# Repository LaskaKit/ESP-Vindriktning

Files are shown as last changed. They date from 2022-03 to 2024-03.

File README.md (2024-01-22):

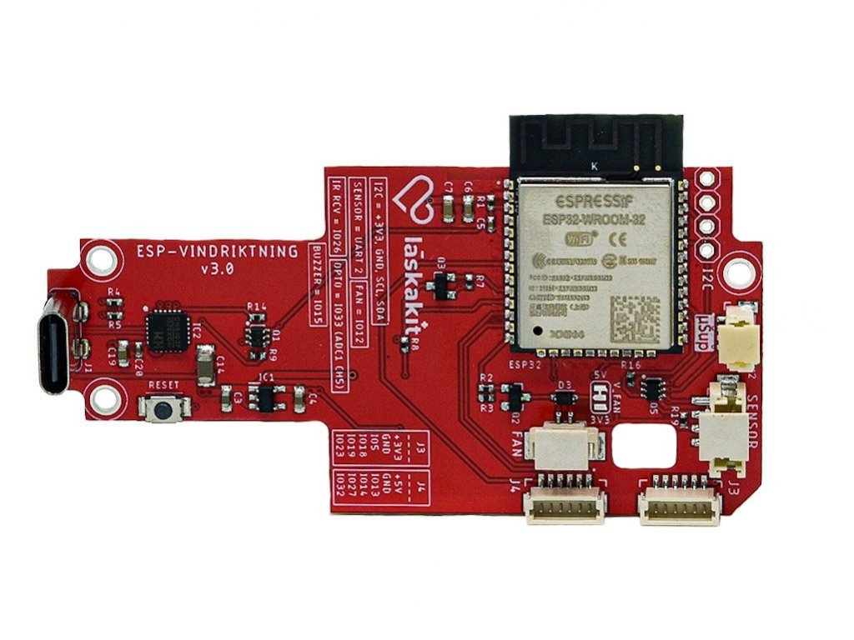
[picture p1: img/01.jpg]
LASKAKIT ESP-VINDRIKTNING

# LASKAKIT ESP-VINDRIKTNING

Ikea Vindriktning is very good and really cheap product which is able to show the quality of air in the room by three LEDs. The original Vindriktning just measure the dust. 
It is not so much for customer. 

We decided to create our own replaced board what will be compatible with the original board but add with Wi-Fi and Bluetooth connectivity, optionaly more sensors, and addressable LEDs. Thanks to this, you get powerful product what may measure the quality of air in the details. 

## Programming
The LASKAKIT ESP-VINDRIKTNING as well as Ikea Vindriktning includes USB-C connector. The orginal board is using the USB-C just for power supply, the ESP-VINDRIKTNING is using USB-C for power and also for programming, because the board includes built-in USB-UART IC as programmer. 

## Connectors
The LASKAKIT ESP-VINDRIKTNING contains six connectors. Two of them are used for original dust sensor - sensor and fan. The third connector is called μŠup and it is compatible with STEMMA QT and Qwiic JST-SH. Thanks to this connector, you can add [temperature/humidity sensor SHT40](https://www.laskakit.cz/laskakit-sht40-senzor-teploty-a-vlhkosti-vzduchu/) or [SCD41 (sensor of CO2/temperature/humidity)](https://www.laskakit.cz/laskakit-scd41-senzor-co2--teploty-a-vlhkosti-vzduchu/) and improve the measurement of air. 
Fourth connector is just 4pin header and you can solder what you want. The 4pin connector includes I2C and power supply with 3.3V. 
The reset of the connectors contains power supply (3.3V) and GPIO which you can use for your purpose. Also the hardware SPI may be used from this connector. 

## LEDs
The number of LEDs is the same with original board. The LEDs are RGB and addressable, it means you can define the color on separately each LED. At the end, you can indicate dust on the first LED, CO2 on the second LED and temperature on third LED. 

## Example codes 
For the fastest development, we prepared a few examples where we show how to easily use LASKAKIT ESP-VINDRIKTNING alone or with SCD41
Use "nodemcu-32s" board in ESPHome and "ESP32 Dev Module" in Arduino IDE.

## Link
The product is available on our store https://www.laskakit.cz/laskakit-esp-vindriktning-esp-32-i2c/
Optional parts: 

SCD41 (CO2/temperature/humidity) https://www.laskakit.cz/laskakit-scd41-senzor-co2--teploty-a-vlhkosti-vzduchu/

SHT40 (temperature/humidity) https://www.laskakit.cz/laskakit-sht40-senzor-teploty-a-vlhkosti-vzduchu/

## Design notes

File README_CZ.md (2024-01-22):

LASKAKIT ESP-VINDRIKTNING
# LASKAKIT ESP-VINDRIKTNING

Ikea Vindriktning je zajímavý a levný produkt firmy Ikea, který dokáže měřit kvalitu vzduchu - prašnost ve vzduchu. A to je všechno.

Rozhodli jsme se vytvořit vlastní desku kterou jenom vyměníš - stačí odšroubovat a přišroubovat 7 šroubků. 
Naše deska LASKAKIT ESP-VINDRIKTNING má konektory na stejném místě jako originální deska, ale navíc obsahuje výkonný a populární čip ESP32, který kromě komunikace s čidlem prachu 
disponuje i možností připojení přes Wi-Fi a Bluetooth. Volitelně můžeš dokoupit i další čidla - SHT40 pro měření teploty a vlhkost nebo SCD41 pro měření CO2/teploty/vlhkosti. 

## Programování
LASKAKIT ESP-VINDRIKTNING stejně jako originální Ikea Vindriktning obsahuje USB-C konektor. U originální desky slouží pouze k napájení, u naší desky je kromě napájení možné ho použít i pro programování.
Stačí jí tedy připojit do USB konektoru a otevřít třeba Arduino IDE. 

## Konektory
LASKAKIT ESP-VINDRIKTNING obsahuje celkem šest konektorů. První dva slouží k připojení originální čidla - čidla prašnosti (čidlo a ventilátor). Třetí [konektor je μŠup](https://blog.laskarduino.cz/predstavujeme-univerzalni-konektor-pro-propojeni-modulu-a-cidel-%ce%bcsup/),
který je kompatibilní s STEMMA QT a Qwiic JST-SH
Díky tomuto konektoru můžeš přidat čidlo [tepoty/vlhkosti SHT40](https://www.laskakit.cz/laskakit-sht40-senzor-teploty-a-vlhkosti-vzduchu/) nebo [SCD41 (čidlo CO2/teploty/vlhkosti)](https://www.laskakit.cz/laskakit-scd41-senzor-co2--teploty-a-vlhkosti-vzduchu/) 
a vytvořit tak komplexní měření kvality vzduchu.
Čtvrtým konektorem je prostý 4pinový hřebínek s I2C a napájením (3.3V)
Zbylé dva konektory obsahují GPIO a 3.3V napájení. GPIO je možné využít s hardwarovým SPI k připojení například displeje. 

## LEDky
Počet LEDek je stejný jako u původní desky. LEDky jsou ale RGB a adresovatelné, to znamená, že každá LEDka dokáže měnit barvu dle dat poslaných přes jednovodičovou sběrnici,
takže první LED může indikovat koncentraci CO2, druhá teplotu, třetí prašnost. 

## Vzorové kódy 
Pro rychlejší start s LASKAKIT ESP-VINDRIKTNING jsme napsali několik vzorových kódů, které můžeš jednoduše upravit pro vlastní potřeby.
Zároveň jsme rozsáhlý článek i na náš blog - https://blog.laskarduino.cz/senzor-prachovych-castic-ikea-vindriktning-vylepseny-o-cidlo-co2-teploty-vlhkosti-bluetooth-wi-fi-komunikaci-a-s-vizualizaci-dat-na-tmep-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
Použij desku "nodemcu-32s" v ESPHome a "ESP32 Dev Module" v Arduino IDE.

## Odkaz
Deska je dostupná na našem e-shopu https://www.laskakit.cz/laskakit-esp-vindriktning-esp-32-i2c/
Další volitelné části: 

SCD41 (CO2/teplota/vlhkost) https://www.laskakit.cz/laskakit-scd41-senzor-co2--teploty-a-vlhkosti-vzduchu/

SHT40 (teplota/vlhkost) https://www.laskakit.cz/laskakit-sht40-senzor-teploty-a-vlhkosti-vzduchu/

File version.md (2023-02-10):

### Version 3.0
- Added, buzzer - GPIO2 pin | Přidán pasivní piezo bzučák - pin GPIO2
- Added, IR remote control receiver - GPIO26 pin | Přidán přijímač IR dálkového ovládání - pin GPIO26
- Added, a jumper to change voltage for fan to 3.3V | Přidána propojka pro přepnutí ventilátoru PM senzoru na 3,3V
- Changed the design of the level converter for the PM sensor | Změna konstrukce převodníku úrovní pro PM senzor
- Changed the USB converter to CH9102F | Změna USB převodníku na CH9102F
- Changed the value of resistor R8 in the logic level converter for the WS2812 LED | Změna hodnoty rezistoru R8 v převodníku logických úrovní pro LED WS2812
- Changed the phototransistor to another type - PT26-51B/TR8 | Změna fototranzistoru na jiný typ - PT26-51B/TR8
- Changed  LDO - BL8071CLBTR33 | Změna LDO stabilizátoru - BL8071CLBTR33
#### Version 2.1
- Phototransistor pin changed from GPIO4 to GPIO33 (ADC1_CHANNEL_5) - cause ADC2 (GPIO4) is not available when using WiFi | Změna pinu fototranzistoru z GPIO4 na GPIO33 (ADC1_CHANNEL_5) - ADC2 (GPIO4) není dostupné při používání WiFi
#### Version 2.0
- Logic level converter for LEDs added | Přidán převodník logické úrovně pro LED

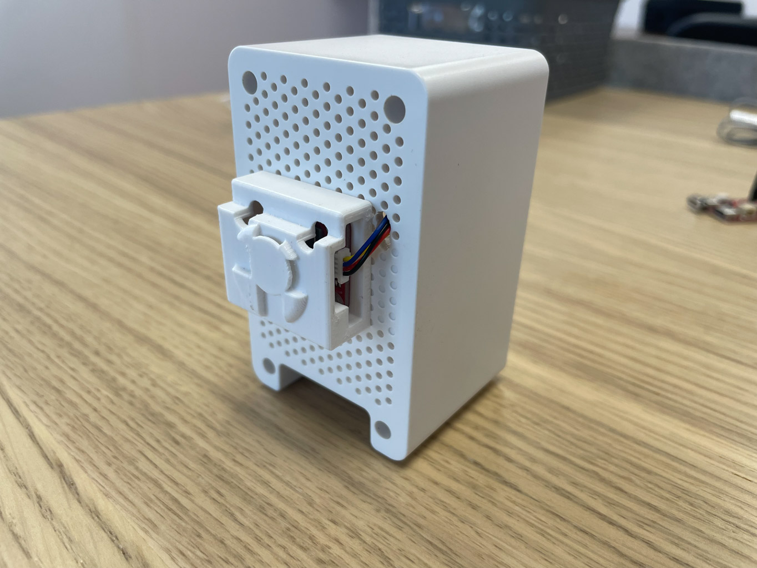
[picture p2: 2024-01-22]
3D/SCD41-on-Vinr.jpg

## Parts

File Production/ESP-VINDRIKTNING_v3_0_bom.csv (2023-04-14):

Comment | Designator | Footprint | LCSC Part #
1.25-2P | FAN | 1.25-2P | C393945
1N5819WS | D3 | SOD323-R | C191023
1k | R8 | R0402
1uF | C3 | C0603
4 7uF | C4 | C0603 | C19666
5k1 | R4 R5 | R0402
10k | R1 R2 R7 R9 R14 R16 R18 R19 | R0402
22uF | C19 | C0603
47uF | C7 | C0603
100k | R3 | R0402
100n | C20 | C0402
100nF | C5 | C0402
100nF | C6 | C0603
100uF | C14 | C1206 | C15008
1x4P-ZH | SENSOR | 1x4P-ZH | C145997
BL8071CLBTR33 | IC3 | SOT223 | C2763399
BSD840NH6327 | Q5 | SC70-6 | C151516
BSS138 | Q2 Q3 | SOT23-3 | C78284
CH9102F | IC2 | QFN24-4X4
ESP32-WROOM-32D | ESP32 | ESP32WROOM32D | C529578
JST-SH-4_VERT | J2 | 1X04_1MM_RA_VERT | C371588
JST-SH-6_VERT | J3 J4 | 1X06_1MM_RA_VERT | C145963
MMDT3904 | Q1 | SC70-6 | C268586
TS-1088R-02026 | RESET | TS1088R02026
1N5819WS | D5 | SOD323-R
2.2uF | C18 | C0402
10k | R10 R12 R13 R17 | R0402
47k | R6 | R0402
100k | R11 | R0402
100n | C8 C11 C12 C13 | C0402
220 | R15 | R0402
BSS138 | Q4 | SOT23-3
FUET-5020 | SG1 | FUET-5020 | C391029
IRM-H638T/TR2 | IR1 | SMD-4_4.0X5.0X2.54P
PT26-21B/CT | PT1 | 1206 | C142317
WS2812B | D1 D2 D4 | WS2812B_2020 | C965555
918-418K2022Y40000 | J1 | 918-418K2022Y40000 | C168704

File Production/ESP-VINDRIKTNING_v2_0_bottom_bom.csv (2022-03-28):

Comment | Designator | Footprint | LCSC Part #
47k | R6 | R0402
100n | C8 C11 C12 C13 | C0402
PT26-21B/TR8 | PT1 | PT26-21B/TR8 | C131248
WS2812B | D1 D2 D4 | WS2812B_2020 | C965555

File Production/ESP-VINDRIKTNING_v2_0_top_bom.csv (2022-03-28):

Comment | Designator | Footprint | LCSC Part #
1.25-2P | FAN | 1.25-2P | C393945
1N5819WS | D3 | SOD323-R | C191023
1uF | C3 | C0603
4 7uF | C4 | C0603 | C19666
5.1k | R4 R5 | R0402 | C25905
10k | R1 R2 R7 R8 R9 R14 | R0402
10μF | C17 | C0603
12MHz | Q6 | 3.2X2.5_KX-7 | C97242
20p | C1 C2 | C0402
47uF | C7 | C0603
100k | R3 | R0402
100n | C9 C10 C15 | C0603
100nF | C5 | C0402
100nF | C6 | C0603
100uF | C14 | C1206 | C15008
470 | R18 R19 | R0402
A1501WV-S-4P | SENSOR | A1501WV-S-4P | C225162
BSS138 | Q2 Q3 | SOT23-3 | C78284
CH340C | IC3 | SOIC16
ESP32-WROOM-32D | ESP32 | ESP32WROOM32D | C82899
HT7833 | LDO | SOT23-5
JST-SH-4_VERT | J2 | 1X04_1MM_RA_VERT | C371588
JST-SH-6_VERT | J3 J4 | 1X06_1MM_RA_VERT | C145963
MMDT3904 | Q1 | SC70-6 | C268586
PI4ULS5V202UEX | IC1 | MSOP8 | C481697
TS-1088R-02026 | RESET | TS1088R02026
918-418K2022Y40000 | J1 | 918-418K2022Y40000 | C168704

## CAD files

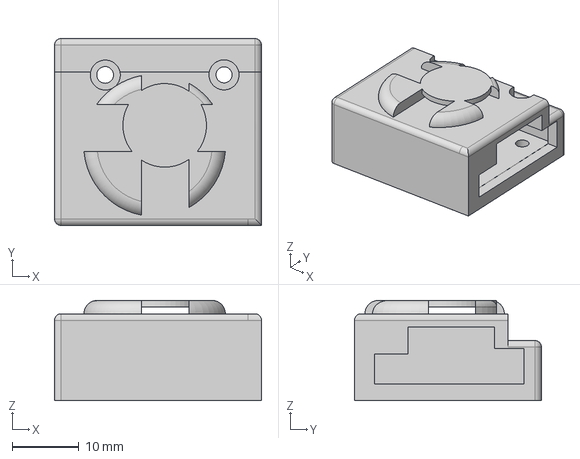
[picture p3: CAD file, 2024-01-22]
3D/LaskaKit SCD41-CO2-Sensor for Vindr.step
31.0 x 28.0 x 15.0 mm

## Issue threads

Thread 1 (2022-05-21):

ESP home

vojtechBohman, 2022-05-21:
Could you show the same integration also for ESP Home?
So far I have only basics. For example on_value_range with PM sensor does not work for me.
```
esphome:
  name: ikea-vindriktning

esp32:
  board: esp32dev
  framework:
    type: arduino

# Enable logging
logger:

# Enable Home Assistant API
api:

ota:
  password: ""

wifi:
  ssid: !secret wifi_ssid
  password: !secret wifi_password

  # Enable fallback hotspot (captive portal) in case wifi connection fails
  ap:
    ssid: "Ikea-Vindriktning"
    password: ""

captive_portal:

uart:
  rx_pin: GPIO16
  tx_pin: GPIO17
  baud_rate: 9600

sensor:
  - platform: pm1006
    id: "vindriktning_pm"
    pm_2_5:
      name: "Particulate Matter 2.5µm Concentration"
    update_interval: 20s
    #on_value_range:
    #  above: 5
    #  below: 10
    #  then:
    #    - light.turn_on: vindriktning_light_1

switch:
  - platform: gpio
    pin: GPIO12
    name: "Fan"
    id: "vindriktning_fan"

light:
  - platform: neopixelbus
    type: GRB
    variant: WS2812
    pin: GPIO25
    num_leds: 3
    name: "Vindriktning Light"
    id: "vindriktning_light"
```

petus, 2022-05-23:
Hello @vojtechBohman , I found that ESPhome is supporting PM1006 (dust sensor) https://esphome.io/components/sensor/pm1006.html
You should just change the GPIO where is UART TX (of PM1006) connected

Konstantin-G, 2022-06-01:
Hi, @bruxy70 did add configuration for ESPHome ;)

Closed 2022-06-01.

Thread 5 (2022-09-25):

Fan noise

magtimmermans, 2022-09-25:
Is there a way to lower the fan noise for example connect it to 3.3 v?

Konstantin-G, 2022-09-26:
Maybe?

magtimmermans, 2022-09-26:
Would be nice. Further great product!

magtimmermans, 2022-09-26:
I thought when you run it on 3v3 it runs slower. But I will try your suggestion as well.

Konstantin-G, 2023-01-04:
In V3.0 we added jumper to change FAN voltage.

Closed 2023-01-04.

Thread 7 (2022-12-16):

V3 Board in Production - PT1 Pad  Issue?

ShockStruck, 2022-12-16:
Hello,

I currently have the V3 Board in Production at JLPCB and they are stating the following:

"Seems the packages of the PT1 parts cannot match the corresponding pads on the PCB board, so we are unable to assemble them."

The part they are trying to place is a PT26-21B-TR8.

Anyone else experience a similar roadblock when producing the boards?

Thanks!

ShockStruck, 2022-12-16:
Latest update from JLPCB:

"Our engineer said the part you choose is correct, but the PCB file is wrong."

Perhaps the V3 Gerber files has some spacing issues on the PT1 pads?

Konstantin-G, 2022-12-17:
PT1 were not designed exactly for this layout, but there no problems whatsoever, we made 500pcs old version. You can replace it with C55976, so we will do to...

Closed 2022-12-17.

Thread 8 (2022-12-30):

V3 Design - VFAN?

ShockStruck, 2022-12-30:
Hello,

Just received 6 PCB's of the V3 varient from JLPCB. Couldn't help but notice that there's no SMD component where labeled "V FAN" 5v/3.3v. is there supposed to be something there? I looked at v2 Schematics, V3 bom and V3 cpl, it appears to not be mentioned . Also noticed that when using the code provided for ESPHome, the lights do not illuminate on the unit. I have found code from bruxy70 on GitHub that resolved this issue.

I should mention that I desoldered the sensor connector from my IKEA boards and placed them into the V3 Board as the connector was backordered.

Thanks for all your help!

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

Konstantin-G, 2023-01-04:
The version 3.0 board is not yet in production and has not been tested. She got onto GitHub by mistake.
V_FAN is a jumper that allows you to power the fan with a voltage of 5V or 3.3V. At 3.3V, the fan has lower rpm and less noise. It has not yet been tested whether switching to 3.3V has any effect on the accuracy of the measurement. By default, the jumper is set to 5V. So there is no need to deal with it.
I have been testing the ESPHome code here for a long time and there is no problem with it. The LEDs are only activated after the sun rises and turn off at sunset. It receives this data from Homeassistant. It might want to fine-tune min_brightness, because at the default value of 0.1 the LED does not light up. We have not yet had the opportunity to examine it in detail and possibly modify it.

Closed 2023-01-04.

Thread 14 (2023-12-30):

Missing files in basic example

ridercz, 2023-12-30:
The `pm1006.h` and `pm1006.cpp` files are missing in basic Arduino example (`VINDRIKTNING`). All other examples have them, but this one does not.

Closed 2024-01-05.

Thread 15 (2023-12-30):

Basic example requires optional CO2 sensor

ridercz, 2023-12-30:
The most basic example (`VINDRIKTNING`) requires optional CO2 sensor. If the sensor is not present, it shows an error.

I think that the basic example should work without any additional hardware and basically mimic the behavior of unmodified unit, so people can build on that example.

Closed 2024-01-05.

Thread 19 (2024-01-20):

Pm1006 measurement fails with basic example

markuswebert, 2024-01-20:
Hi,

I own two VINDRIKTNING ESP v3 boards and two IKEA sensors. When replacing the original board with the laskakit v3 (running the VINDRIKTNING.ino flashed via Arduino IDE) and connecting the pm1006 sensor (power and fan cables), I am not able to read the sensor measurements while starting am stopping the fan as well as reading the ambient light value seems to work. When reading the pm1006 sensor, the log always states Fan ON, measurement failed, fan off.

In the arduino IDE, I set the board ESP32 DEV Module. I also tried both laskakit boards with both ikea sensors.

Do you have a hint for me on how to solve that? Thanks!

Bascht74, 2024-01-20:
I am using this configuration for esphome

`substitutions:
  devicename: luftegwohnzimmer
  upper_devicename: Luftsensor EG Wohnzimmer
  device_description: "IKEA LaskaKit ESP-VINDRIKTNING ESP-32 I2C"

globals:
   - id: max_brightness
     type: float
     restore_value: no
     initial_value: '0.5'
   - id: min_brightness
     type: float
     restore_value: no
     initial_value: '0.1'

esphome:
  name: ${devicename}
  friendly_name: ${upper_devicename}
  comment: "${device_description}"
  on_boot:
    priority: 240
    then:
        - light.turn_on:
            id: status
            brightness: 0%

esp32:
  board: nodemcu-32s
  framework:
    type: esp-idf

logger:
  baud_rate: 0

api:
  reboot_timeout: 240min
  encryption:
    key: !secret encryption_key

ota:
  password: !secret ota_password

wifi:
  reboot_timeout: 10min
  ssid: !secret wifi_ssid
  password: !secret wifi_password
  power_save_mode: none
  use_address: 192.168.175.237

uart:
  rx_pin: 16
  tx_pin: 17
  baud_rate: 9600
  id: uart_2

i2c:
  sda: 21
  scl: 22
  scan: true
  id: bus_a

sensor:
  - platform: homeassistant
    id: sun_elevation
    entity_id: sun.sun
    internal: true
    attribute: elevation

  - platform: pm1006
    uart_id: uart_2
    update_interval: 20s
    pm_2_5:
      name: "PM 2.5µm"
      id: pm
      state_class: "measurement"
      device_class: "pm25"
      unit_of_measurement: 'µg/m³'
      accuracy_decimals: 0
      filters:
        - throttle_average: 120s
      on_value:
        then:
        - if:
            condition:
              lambda: 'return x < 30;'
            then:
              - light.addressable_set:
                  id: status
                  range_from: 0
                  range_to: 0
                  red: 0.0
                  green: 1.0
                  blue: 0.0
                  color_brightness:  !lambda |-
                    return id(sun_elevation).state > 0 ? id(max_brightness) : id(min_brightness);
            else:
            - if:
                condition:
                  lambda: 'return x > 90;'
                then:
                - light.addressable_set:
                    id: status
                    range_from: 0
                    range_to: 0
                    red: 1.0
                    green: 0.0
                    blue: 0.0
                    color_brightness:  !lambda |-
                      return id(sun_elevation).state > 0 ? id(max_brightness) : id(min_brightness);
                else:
                - light.addressable_set:
                    id: status
                    range_from: 0
                    range_to: 0
                    red: 1.0
                    green: 0.72
                    blue: 0.0
                    color_brightness:  !lambda |-
                      return id(sun_elevation).state > 0 ? id(max_brightness) : id(min_brightness);
        - switch.turn_on: fan_delay

  - platform: scd4x
    co2:
      name: "CO2"
      state_class: "measurement"
      device_class: "carbon_dioxide"
      unit_of_measurement: "ppm"
      accuracy_decimals: 0
      filters:
        - throttle_average: 120s
      id: co2
      on_value:
        then:
        - if:
            condition:
              lambda: 'return x < 1000;'
            then:
              - light.addressable_set:
                  id: status
                  range_from: 1
                  range_to: 1
                  red: 0.0
                  green: 1.0
                  blue: 0.0
                  color_brightness:  !lambda |-
                    return id(sun_elevation).state > 0 ? 1.0 : 0.5;
            else:
            - if:
                condition:
                  lambda: 'return x > 1500;'
                then:
                - light.addressable_set:
                    id: status
                    range_from: 1
                    range_to: 1
                    red: 1.0
                    green: 0.0
                    blue: 0.0
                    color_brightness:  !lambda |-
                      return id(sun_elevation).state > 0 ? 1.0 : 0.5;
                else:
                - light.addressable_set:
                    id: status
                    range_from: 1
                    range_to: 1
                    red: 1.0
                    green: 0.72
                    blue: 0.0
                    color_brightness:  !lambda |-
                      return id(sun_elevation).state > 0 ? 1.0 : 0.5;

    humidity:
      name: "Luftfeuchtigkeit"
      id: humidity
      state_class: "measurement"
      device_class: "humidity"
      unit_of_measurement: '%'
      filters:
        - throttle_average: 120s
      on_value:
        then:
        - if:
            condition:
              lambda: 'return x < 30;'
            then:
              - light.addressable_set:
                  id: status
                  range_from: 2
                  range_to: 2
                  red: 1.0
                  green: 0.0
                  blue: 0.0
                  color_brightness:  !lambda |-
                    return id(sun_elevation).state > 0 ? 1.0 : 0.5;
            else:
            - if:
                condition:
                  lambda: 'return x > 60;'
                then:
                - light.addressable_set:
                    id: status
                    range_from: 2
                    range_to: 2
                    red: 0.0
                    green: 0.0
                    blue: 1.0
                    color_brightness:  !lambda |-
                      return id(sun_elevation).state > 0 ? 1.0 : 0.5;
                else:
                - light.addressable_set:
                    id: status
                    range_from: 2
                    range_to: 2
                    red: 0.0
                    green: 1.0
                    blue: 0.0
                    color_brightness:  !lambda |-
                      return id(sun_elevation).state > 0 ? 1.0 : 0.5;
    temperature:
      name: "Temperatur"
      state_class: "measurement"
      device_class: "temperature"
      unit_of_measurement: '°C'
      filters:
        - throttle_average: 120s

button:
  - platform: restart
    name: Restart
    disabled_by_default: true
    entity_category: diagnostic

switch:
  - platform: gpio
    pin: 12
    id: fan
    internal: true
    restore_mode: ALWAYS_ON
    disabled_by_default: true
    entity_category: diagnostic

  - platform: template
    entity_category: diagnostic
    disabled_by_default: true
    internal: true
    id: fan_delay
    turn_on_action:
      - switch.turn_off: fan
      - delay: 50s
      - switch.turn_on: fan

light:
  - platform: esp32_rmt_led_strip
    rgb_order: GRB
    chipset: WS2812
    internal: true
    rmt_channel: 0
    pin: GPIO25
    num_leds: 3
    id: status`

markuswebert, 2024-01-21:
Choosing the right board (nodemcu-32s) did the trick! Thanks @Bascht74 for sharing your config!

Maybe it is worth adding this to the readme? Seems to be relevant for both ESPHome and Arduino.

Konstantin-G, 2024-01-22:
added, thanks

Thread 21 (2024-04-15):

Question: Would work with IKEA VINDSTYRKA as well?

vsisl, 2024-04-15:
Hi,

Would the [LaskaKit ESP-VINDRIKTNING ESP-32 I2C board](https://www.laskakit.cz/laskakit-esp-vindriktning-esp-32-i2c/) (and the codebase) also work with the [IKEA VINDSTYRKA](https://www.ikea.com/cz/cs/p/vindstyrka-senzor-kvality-vzduchu-chytre-40498234/) device?

Konstantin-G, 2024-04-16:
We have no idea. Don't have VINDSTYRKA to check and test.

vsisl, 2024-04-16:
Thanks for a quick reply @Konstantin-G !

I have the VINDSTYRKA device. If there was interest from LaskaKit, I could test if it works with your board. I'm based in Czech Rep.

Konstantin-G, 2024-04-17:
Yeah , sure, it would nice

Closed 2024-04-16.

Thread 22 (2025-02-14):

KiCad source files

mdimjasevic, 2025-02-14:
This project is very exciting! I've been mod'ing the IKEA sensor myself and I ran into your project. It seems to almost exactly match what I'd like to do.

Would you be so kind to share your KiCad source code files?

Konstantin-G, 2025-02-17:
Sorry, we not using KiCad.

mdimjasevic, 2025-02-17:
Thank you for the clarification. What do you use and can you share the source files for that program?

Konstantin-G, 2025-02-18:
Only schematic, here.

Closed 2025-02-17.

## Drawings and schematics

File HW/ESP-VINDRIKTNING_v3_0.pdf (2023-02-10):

IO0 | 25 IO4 | 26 IO16 | 27 IO17 | 28 IO5 | 29 IO18 | 30 IO19 | 31 NC | 32 IO21 | 33 RXD0 | 34 TXD0 | 35 IO22 | 36 IO23 | 37 GND3 | 38 P_GND | 39
IC2 | - +

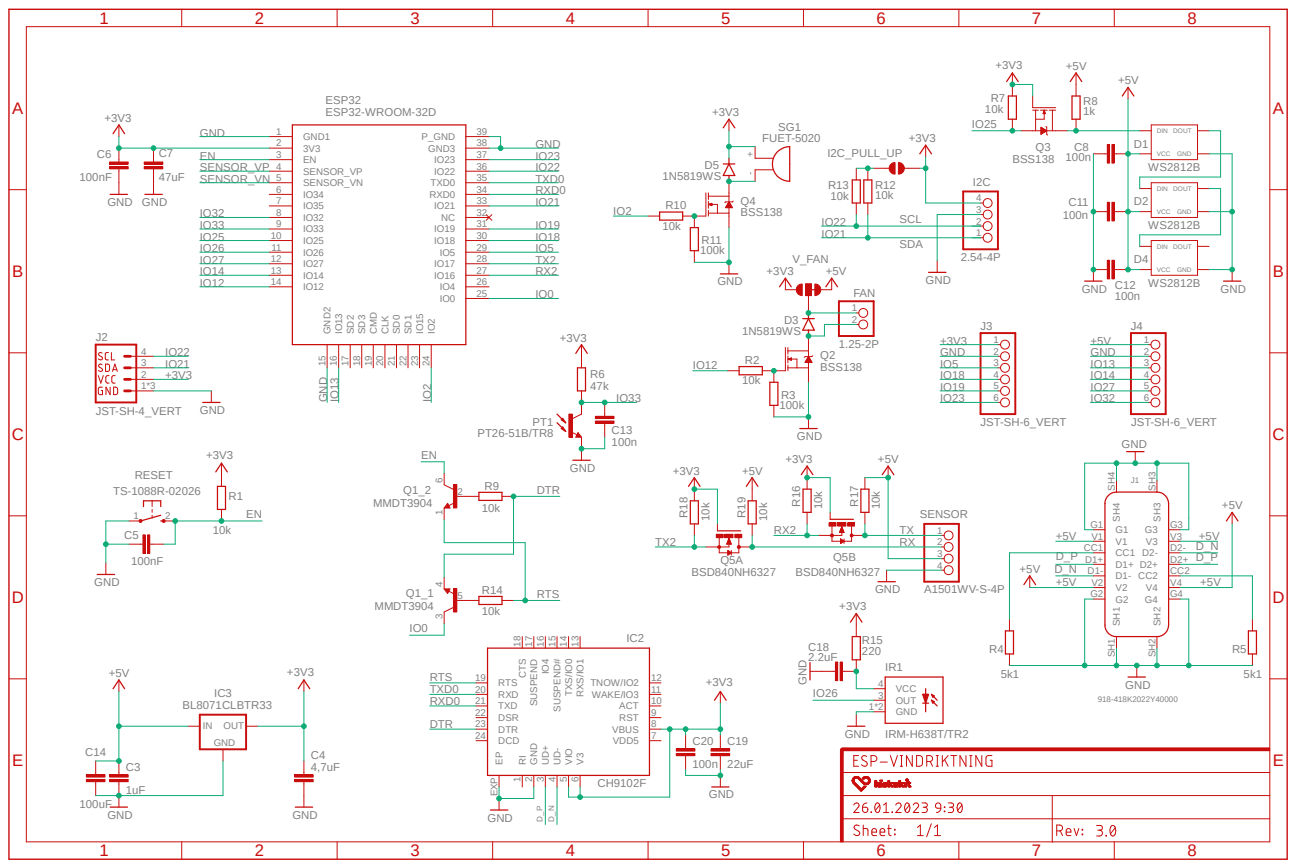
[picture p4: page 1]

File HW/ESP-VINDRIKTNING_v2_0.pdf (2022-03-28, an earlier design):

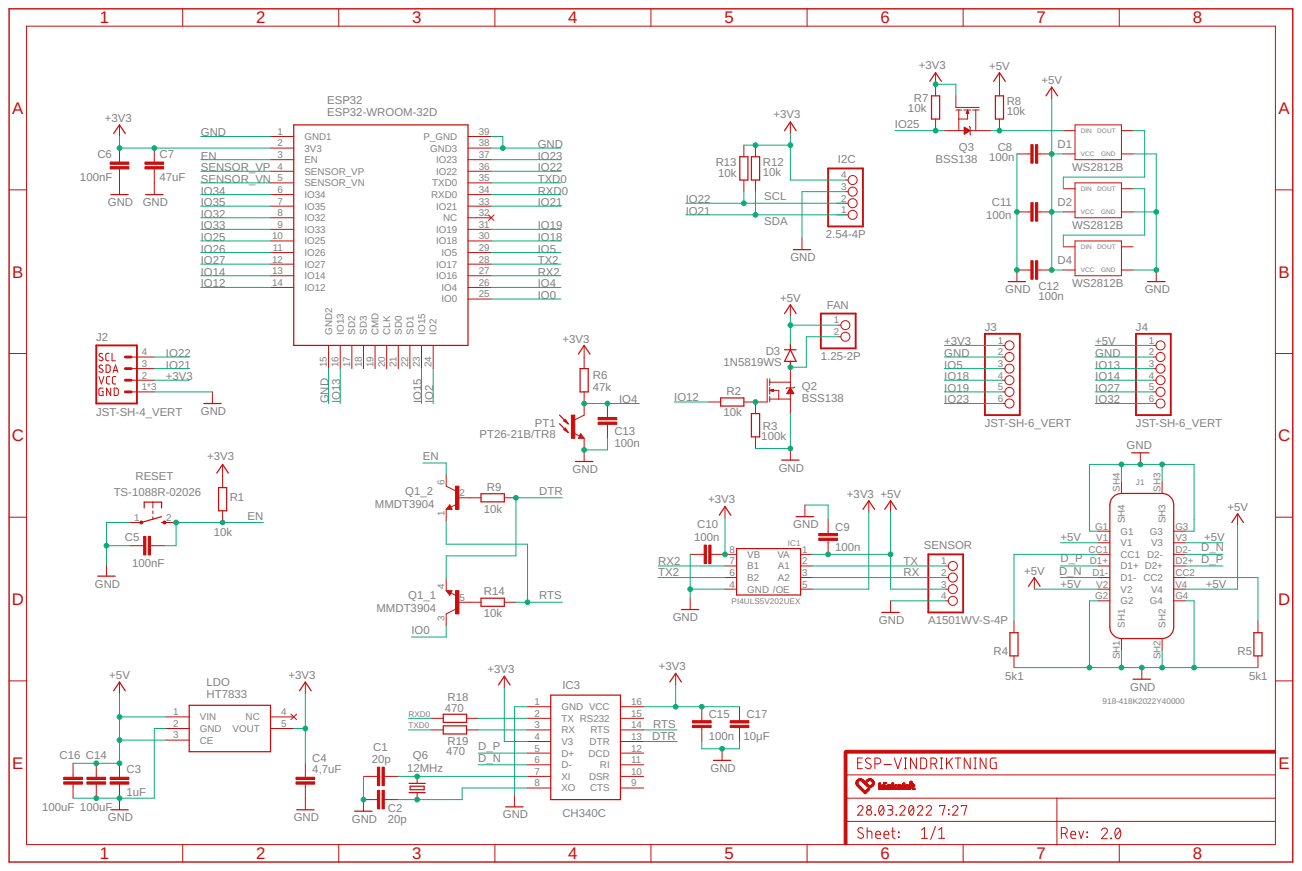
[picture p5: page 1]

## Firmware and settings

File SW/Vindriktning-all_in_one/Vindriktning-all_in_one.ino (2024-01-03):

/*
* Vzorovy kod od laskakit.cz pro LaskaKit ESP-VINDRIKTNING
* Kod podporuje cidla: SCD41 (CO2, teplota a vlhkost) nebo SHT40 (teplota a vlhkost)
* Kod podporuje posilani dat na: server TMEP.cz nebo seriovy port (UART)
*
* TMEP.cz momentalne neumi zobrazovat ctyri veliciny najednou - prasnost, CO2, teplota, vlhkost. 
* Proto jsou zaregistrovana dve cidla zvlast - prasnost (cidlo PM1006) a CO2/teplota/vlhkost (cidlo SCD41)
* Pokud pouzijete cidlo SHT40 bude vam stacit pouze jedno registrovane cidlo
*
* LaskaKit ESP-VINDRIKTNING (https://www.laskakit.cz/laskakit-esp-vindriktning-esp-32-i2c/)
* LaskaKit SCD41 Senzor CO2, teploty a vlhkosti vzduchu (https://www.laskakit.cz/laskakit-scd41-senzor-co2--teploty-a-vlhkosti-vzduchu/)
* LaskaKit SHT40 Senzor teploty a vlhkosti vzduchu (https://www.laskakit.cz/laskakit-sht40-senzor-teploty-a-vlhkosti-vzduchu/)
*
* Vytvoreno (c) laskakit.cz 2022
* Upravil @cqeta1564
*
* Potrebne knihovny:
* https://github.com/adafruit/Adafruit_SHT4X //SHT40
* https://github.com/sparkfun/SparkFun_SCD4x_Arduino_Library //SCD41
* https://github.com/bertrik/pm1006 //PM1006
*/

/*--------------------- UPRAV NASTAVENI ---------------------*/
const char* ssid = "SSID";
const char* password = "PASSWORD";

// pokud NEpouzivas cidlo SCD41, tak vypln pouze prvni adresu - teplota, vlhkost a prasnost
String hlavni = "http://HLAVNI_DOMENA.tmep.cz/index.php?";

// pokud pouzivas cidlo SCD41, tak vypln i tuto adresu
// hodnoty budou rozdeleny nasledovne: prvni adresa - teplota, vlhkost a co2
//                                     druha adresa - prasnost
String sekundarni = "http://SEKUNDARNI-DOMENA.tmep.cz/index.php?";

// Interval mereni (zadavano v milisekundach)
#define SLEEP_SEC 300000

// zapnout seriovy port (UART)
#define uart

// zapnout server TMEP.cz
//#define tmep

// zapnout SCD41
//#define scd41 

// zapnout SHT40
//#define sht40

// zapnout OLED displej
//#define oled
/*------------------------ KONEC UPRAV -----------------------*/

#include <Wire.h>

/* TMEP.cz */
#ifdef tmep
#include <WiFi.h>
#include <HTTPClient.h>
#endif

/* SHT40 */
#ifdef sht40
#include "Adafruit_SHT4x.h"
#endif

/* OLED Dislpej */
#ifdef oled
#include <SPI.h>
#include <Adafruit_GFX.h>
#include <Adafruit_SSD1306.h>
#endif

/* LaskaKit ESP-VINDRIKTNING s čidlem CO2/teploty/vlhkosti SCD41 */
#ifdef scd41
#include "SparkFun_SCD4x_Arduino_Library.h"
#endif

/* LaskaKit ESP-VINDRIKTNING - cidlo prasnosti PM1006 */
#include "pm1006.h"

/* RGB adresovatelne LED */
#include <Adafruit_NeoPixel.h>

/* LaskaKit ESP-VINDRIKTNING - cidlo prasnosti PM1006 */
#define PIN_FAN 12 // spinani ventilatoru
#define RXD2 16 // UART - RX
#define TXD2 17 // UART - TX

/* Nastaveni RGB LED */
#define BRIGHTNESS 100
#define PIN_LED 25
#define PM_LED 0
#define TEMP_LED 1
#define CO2_LED 2

/* OLED nastaveni */
#ifdef oled
#define SCREEN_WIDTH  128 // OLED display width, in pixels
#define SCREEN_HEIGHT 32 // OLED display height, in pixels
#define OLED_RESET    -1 // Reset pin # (or -1 if sharing Arduino reset pin)
#define SCREEN_ADDRESS 0x3C ///< See datasheet for Address; 0x3D for 128x64, 0x3C for 128x32
Adafruit_SSD1306 display(SCREEN_WIDTH, SCREEN_HEIGHT, &Wire, OLED_RESET);

const unsigned char laskakit [] PROGMEM = {
	0x01, 0xf0, 0x00, 0x1f, 0x00, 0x00, 0x00, 0x00, 0x00, 0x00, 0x00, 0x00, 0x00, 0x00, 0x00, 0x00, 
	0x07, 0xfc, 0x00, 0x3f, 0xc0, 0x00, 0x00, 0x00, 0x00, 0x00, 0x00, 0x00, 0x00, 0x00, 0x03, 0x00, 
	0x0f, 0xfe, 0x00, 0x7f, 0xe0, 0x00, 0x00, 0x00, 0x00, 0x00, 0x00, 0x00, 0x00, 0x00, 0x03, 0x00, 
	0x1e, 0x0f, 0x00, 0xf0, 0xf0, 0x00, 0x00, 0x00, 0x00, 0x00, 0x00, 0x00, 0x00, 0x00, 0x0f, 0xc0, 
	0x3c, 0x07, 0x80, 0xe0, 0x78, 0x00, 0x00, 0x0f, 0xc0, 0x00, 0x00, 0x00, 0x00, 0x00, 0x03, 0x00, 
	0x78, 0x03, 0xc0, 0x00, 0x3c, 0x00, 0x38, 0x0f, 0xc0, 0x03, 0x80, 0x00, 0x03, 0x80, 0x03, 0x00, 
	0x70, 0x01, 0xe0, 0x00, 0x1c, 0x00, 0x38, 0x00, 0x00, 0x03, 0x80, 0x00, 0x03, 0x80, 0x00, 0x00, 
	0xe0, 0x00, 0xf0, 0x00, 0x0e, 0x00, 0x38, 0x00, 0x00, 0x03, 0x80, 0x00, 0x03, 0x80, 0x00, 0x30, 
	0xe0, 0x00, 0x78, 0x00, 0x0e, 0x00, 0x38, 0x00, 0x00, 0x03, 0x80, 0x00, 0x03, 0x80, 0x00, 0x30, 
	0xe0, 0x00, 0x3c, 0x00, 0x0e, 0x00, 0x38, 0xfe, 0x0f, 0xe3, 0x8f, 0x1f, 0xc3, 0x8f, 0x1c, 0x7c, 
	0xe0, 0x00, 0x1e, 0x00, 0x0e, 0x00, 0x38, 0xff, 0x1f, 0xe3, 0x9e, 0x1f, 0xe3, 0x9e, 0x1c, 0x7c, 
	0x70, 0x00, 0x0f, 0x00, 0x1c, 0x00, 0x38, 0x03, 0x9c, 0x03, 0xbc, 0x00, 0xe3, 0xbc, 0x1c, 0x30, 
	0x78, 0x00, 0x07, 0x80, 0x3c, 0x00, 0x38, 0x03, 0x9e, 0x03, 0xf8, 0x00, 0xe3, 0xf8, 0x1c, 0x30, 
	0x3c, 0x00, 0x03, 0xc0, 0x78, 0x00, 0x38, 0xff, 0x8f, 0xe3, 0xf8, 0x1f, 0xe3, 0xf8, 0x1c, 0x30, 
	0x1e, 0x00, 0x01, 0xe0, 0xf0, 0x00, 0x39, 0xc3, 0x80, 0xf3, 0xfc, 0x38, 0xe3, 0xfc, 0x1c, 0x30, 
	0x0f, 0x00, 0x00, 0xff, 0xe0, 0x00, 0x39, 0xc3, 0x80, 0x73, 0x9e, 0x38, 0xe3, 0x9e, 0x1c, 0x30, 
	0x07, 0x80, 0x00, 0x7f, 0xc0, 0x00, 0x39, 0xff, 0x9f, 0xe3, 0x8f, 0x3f, 0xe3, 0x8f, 0x1c, 0x3e, 
	0x03, 0xc0, 0x00, 0x1f, 0x00, 0x00, 0x38, 0xff, 0x9f, 0xc3, 0x87, 0x1f, 0xe3, 0x87, 0x1c, 0x1e, 
	0x01, 0xe0, 0x00, 0x00, 0x00, 0x00, 0x00, 0x00, 0x00, 0x00, 0x00, 0x00, 0x00, 0x00, 0x00, 0x00, 
	0x00, 0xf0, 0x00, 0x00, 0x00, 0x00, 0x00, 0x00, 0x00, 0x00, 0x00, 0x00, 0x00, 0x00, 0x00, 0x00, 
	0x00, 0x78, 0x00, 0x00, 0x00, 0x00, 0x00, 0x00, 0x00, 0x00, 0x00, 0x00, 0x00, 0x00, 0x00, 0x00, 
	0x00, 0x3c, 0x00, 0x38, 0x00, 0x00, 0x00, 0x00, 0x00, 0x00, 0x00, 0x00, 0x00, 0x00, 0x00, 0x00, 
	0x00, 0x1e, 0x00, 0x78, 0x00, 0x00, 0x20, 0x00, 0x00, 0x00, 0x01, 0x00, 0x00, 0x00, 0x00, 0x00, 
	0x00, 0x0f, 0x00, 0xf0, 0x00, 0x00, 0x20, 0x00, 0x02, 0x00, 0x02, 0x00, 0x00, 0x08, 0x00, 0x00, 
	0x00, 0x07, 0x81, 0xe0, 0x00, 0x00, 0x3a, 0x9f, 0xba, 0xbb, 0x73, 0x66, 0x7e, 0xea, 0xed, 0xc0, 
	0x00, 0x03, 0xc3, 0xc0, 0x00, 0x00, 0x2a, 0x92, 0x8b, 0x2a, 0x62, 0x94, 0x4a, 0x2c, 0xa9, 0x80, 
	0x00, 0x01, 0xe7, 0x80, 0x00, 0x00, 0x29, 0x12, 0xaa, 0xa2, 0x12, 0x94, 0x4a, 0xaa, 0x88, 0x40, 
	0x00, 0x00, 0xff, 0x00, 0x00, 0x00, 0x39, 0x12, 0xb2, 0xba, 0x72, 0x64, 0x4a, 0xca, 0xe9, 0xc0, 
	0x00, 0x00, 0x7e, 0x00, 0x00, 0x00, 0x02, 0x00, 0x00, 0x00, 0x00, 0x00, 0x00, 0x00, 0x00, 0x00, 
	0x00, 0x00, 0x3c, 0x00, 0x00, 0x00, 0x00, 0x00, 0x00, 0x00, 0x00, 0x00, 0x00, 0x00, 0x00, 0x00, 
	0x00, 0x00, 0x18, 0x00, 0x00, 0x00, 0x00, 0x00, 0x00, 0x00, 0x00, 0x00, 0x00, 0x00, 0x00, 0x00, 
	0x00, 0x00, 0x00, 0x00, 0x00, 0x00, 0x00, 0x00, 0x00, 0x00, 0x00, 0x00, 0x00, 0x00, 0x00, 0x00
};
#endif

/* LaskaKit ESP-VINDRIKTNING - cidlo prasnosti PM1006, nastaveni UART2 */
static PM1006 pm1006(&Serial2);

/* LaskaKit ESP-VINDRIKTNING s čidlem CO2/teploty/vlhkosti SCD41 */
#ifdef scd41
SCD4x SCD41;
#endif

/* LaskaKit ESP-VINDRIKTNING s čidlem teploty/vlhkosti SHT40 */
#ifdef sht40
Adafruit_SHT4x sht4 = Adafruit_SHT4x();
#endif

/* RGB adresovatelne LED */
Adafruit_NeoPixel pixels = Adafruit_NeoPixel(3, PIN_LED, NEO_GRB + NEO_KHZ800);

void setup() {
  pinMode(PIN_FAN, OUTPUT); // Ventilator pro cidlo prasnosti PM1006
  Serial.begin(115200);
  Wire.begin();
  
  pixels.begin(); // WS2718
  pixels.setBrightness(BRIGHTNESS);

  delay(10);
  
  /*-------------- RGB adresovatelne LED - zhasni --------------*/
  pixels.setPixelColor(PM_LED, pixels.Color(0, 0, 0)); // R, G, B
  pixels.setPixelColor(TEMP_LED, pixels.Color(0, 0, 0)); // R, G, B
  pixels.setPixelColor(CO2_LED, pixels.Color(0, 0, 0)); // R, G, B
  pixels.show();  // Zaktualizuje barvu

  /*-------------- PM1006 - cidlo prasnosti ---------------*/
  Serial2.begin(9600, SERIAL_8N1, RXD2, TXD2); // cidlo prasnosti PM1006

  /*-------------------- OLED Displej --------------------*/
  #ifdef oled
  // SSD1306_SWITCHCAPVCC = generate display voltage from 3.3V internally
  if(!display.begin(SSD1306_SWITCHCAPVCC, SCREEN_ADDRESS)) {
    Serial.println(F("SSD1306 allocation failed"));
    for(;;); // Don't proceed, loop forever
  }

  // Clear the buffer
  display.clearDisplay();

  display.drawBitmap(0, 0, laskakit, 128, 32, WHITE);
  display.display();
  #endif

  /*------------- SCD41 - CO2, teplota, vlhkost -----------*/
  #ifdef scd41
  // inicializace
  //             begin, autokalibrace
  //               |      |
  if (SCD41.begin(false, true) == false)
  {
    Serial.println("SCD41 nenalezen.");
    Serial.println("Zkontroluj propojeni.");
    while(1)
      ;
  }
 
  // prepnuti do low power modu
  if (SCD41.startLowPowerPeriodicMeasurement() == true)  
  {
    Serial.println("Low power mod povolen.");
  }
  #endif

  /*------------- SHT40 - teplota, vlhkost -----------*/
  #ifdef sht40
  if (! sht4.begin()) 
  {
    Serial.println("SHT4x not found");
    Serial.println("Check the connection");
    while (1) delay(1);
  }

  sht4.setPrecision(SHT4X_HIGH_PRECISION); // highest resolution
  sht4.setHeater(SHT4X_NO_HEATER); // no heater
  #endif

  /*------------- Wi-Fi -----------*/
  #ifdef tmep
  WiFi.begin(ssid, password);
  Serial.println("Pripojovani");
  while(WiFi.status() != WL_CONNECTED) {
    delay(500);
    Serial.print(".");
  }
  Serial.println();
  Serial.print("Pripojeno do site, IP adresa zarizeni: ");
  Serial.println(WiFi.localIP());
  #endif
}
 
void loop() {
  /*------------- SCD41 - CO2, teplota, vlhkost -----------*/
  int co2 = -1;
  float teplota = 9999.0;
  int vlhkost = -1;
  #ifdef scd41 
  while (!SCD41.readMeasurement()) // cekani na nova data (zhruba 30s)
  {
    delay(1);
  } 

  co2 = SCD41.getCO2();
  teplota = SCD41.getTemperature();
  vlhkost = SCD41.getHumidity();
  #endif

  // odeslani hodnot pres UART
  #ifdef uart
  Serial.print("Teplota: "); Serial.print(teplota); Serial.println(" degC");
  Serial.print("Vlhkost: "); Serial.print(vlhkost); Serial.println("% rH");
  Serial.print("CO2: "); Serial.print(co2); Serial.println(" ppm");
  #endif


  /*------------- SHT40 - teplota, vlhkost -----------*/
  #ifdef sht40
  sensors_event_t humidity, temp; // temperature and humidity variables
  sht4.getEvent(&humidity, &temp);

  teplota = temp.temperature;
  vlhkost = humidity.relative_humidity;

  // odeslani hodnot pres UART
  #ifdef uart
  Serial.print("Teplota: ");
  Serial.print(teplota);
  Serial.println(" degC");
  Serial.print("Vlhkost: ");
  Serial.print(vlhkost);
  #endif
  #endif


  /*-------------- PM1006 - cidlo prasnosti ---------------*/
  uint16_t pm2_5;
  digitalWrite(PIN_FAN, HIGH);
  Serial.println("Fan ON");
  delay(30000);

  if (pm1006.read_pm25(&pm2_5)){
    Serial.println("Mam data z cidla");
  } else {
    Serial.println("Data z cisla nesla vycist");
  }


  delay(100);
  digitalWrite(PIN_FAN, LOW);
  Serial.println("Fan OFF");

  // odeslani hodnot pres UART
  #ifdef uart
  Serial.print("PM2.5: "); Serial.print(pm2_5); Serial.println(" ppm");
  #endif
  
  
  /*-------------- RGB adresovatelne LED ---------------*/
  // CO2 LED
  if(co2 < 0){
    pixels.setPixelColor(CO2_LED, pixels.Color(0, 0, 0)); // R, G, B
  }

  if((co2 >= 0) && (co2 < 1000)){
    pixels.setPixelColor(CO2_LED, pixels.Color(0, 255, 0)); // R, G, B
  }
  
  if((co2 >= 1000) && (co2 < 1200)){
    pixels.setPixelColor(CO2_LED, pixels.Color(128, 255, 0)); // R, G, B
  }
  
  if((co2 >= 1200) && (co2 < 1500)){
  pixels.setPixelColor(CO2_LED, pixels.Color(255, 255, 0)); // R, G, B
  }
  
  if((co2 >= 1500) && (co2 < 2000)){
    pixels.setPixelColor(CO2_LED, pixels.Color(255, 128, 0)); // R, G, B
  }
  
  if(co2 >= 2000){
    pixels.setPixelColor(CO2_LED, pixels.Color(255, 0, 0)); // R, G, B
  }

  // teplota LED
  if(teplota < 20.0){
    pixels.setPixelColor(TEMP_LED, pixels.Color(0, 0, 255)); // R, G, B
  }

  if((teplota >= 20.0) && (teplota < 23.0)){
    pixels.setPixelColor(TEMP_LED, pixels.Color(0, 255, 0)); // R, G, B
  }

  if((teplota >= 23.0) && (teplota < 9999)){
    pixels.setPixelColor(TEMP_LED, pixels.Color(255, 0, 0)); // R, G, B
  }

  if(teplota >= 9999){
    pixels.setPixelColor(TEMP_LED, pixels.Color(0, 0, 0)); // R, G, B
  }

  // PM LED
  if(!pm1006.read_pm25(&pm2_5)){
    pixels.setPixelColor(PM_LED, pixels.Color(0, 0, 0)); // R, G, B
  }

  if((pm2_5 >= 0) && (pm2_5 < 30)){
    pixels.setPixelColor(PM_LED, pixels.Color(0, 255, 0)); // R, G, B
  }
  
  if((pm2_5 >= 30) && (pm2_5 < 40)){
    pixels.setPixelColor(PM_LED, pixels.Color(128, 255, 0)); // R, G, B
  }
  
  if((pm2_5 >= 40) && (pm2_5 < 80)){
  pixels.setPixelColor(PM_LED, pixels.Color(255, 255, 0)); // R, G, B
  }
  
  if((pm2_5 >= 80) && (pm2_5 < 90)){
    pixels.setPixelColor(PM_LED, pixels.Color(255, 128, 0)); // R, G, B
  }
  
  if(pm2_5 >= 90){
    pixels.setPixelColor(PM_LED, pixels.Color(255, 0, 0)); // R, G, B
  }
  pixels.show();  // Zaktualizuje barvu


  /*------------- OLED Display -------------*/
  #ifdef oled
  display.clearDisplay();
  display.setTextSize(2);             // Normal 1:1 pixel scale
  display.setTextColor(SSD1306_WHITE);        // Draw white text

  display.setCursor(5,8);             // Start at top-left corner
  display.println(String(pm2_5) + "mg/m3");

  #ifdef sht40
  display.clearDisplay();
  display.setTextSize(1);             // Normal 1:1 pixel scale
  display.setTextColor(SSD1306_WHITE);        // Draw white text

  display.setCursor(69,5);             // Start at top-left corner
  display.println(String(teplota) + "degC");  
  display.setCursor(85,21);             // Start at top-left corner
  display.println(String(vlhkost) + "%");
  display.setCursor(5,21);             // Start at top-left corner
  display.println(String(pm2_5) + "mg/m3");
  #endif

  #ifdef scd41
  display.clearDisplay();
  display.setTextSize(1);             // Normal 1:1 pixel scale
  display.setTextColor(SSD1306_WHITE);        // Draw white text

  display.setCursor(5,5);             // Start at top-left corner
  display.println(String(co2) + "ppm");
  display.setCursor(69,5);             // Start at top-left corner
  display.println(String(teplota) + "degC");  
  display.setCursor(85,21);             // Start at top-left corner
  display.println(String(vlhkost) + "%");
  display.setCursor(5,21);             // Start at top-left corner
  display.println(String(pm2_5) + "mg/m3");
  #endif
  
  

  display.display();  
  delay(1);
  #endif
  

  /*------------ Odeslani hodnot na TMEP.cz ------------------*/
  #ifdef tmep
  #ifdef sht40
  if(WiFi.status()== WL_CONNECTED)
  {
    //GUID, nasleduje hodnota teploty, pro vlhkost "humV", pro CO2 "CO2" cidla SCD41
    String serverPathCO2 = hlavni + "" + "temp" + "=" + teplota + "&humV=" + vlhkost + "&pm=" + pm2_5; 
    sendhttpGet(serverPathCO2);

  }
  else 
  {
    Serial.println("Wi-Fi odpojeno");
  }
  #endif
  #ifdef scd41
  if(WiFi.status()== WL_CONNECTED)
  {
    //GUID, nasleduje hodnota teploty, pro vlhkost "humV", pro CO2 "CO2" cidla SCD41
    String serverPathCO2 = sekundarni + "" + "temp=" + teplota + "&humV=" + vlhkost + "&CO2=" + co2; 
    sendhttpGet(serverPathCO2);

    delay(100);
    int pmOdeslat = pm2_5;
    //GUID, nasleduje hodnota cidla prasnosti PM1006 a odeslani na druhou domenu
    String serverPathPM = hlavni + "" + "pm=" + pmOdeslat; 
    sendhttpGet(serverPathPM);

  }
  else 
  {
    Serial.println("Wi-Fi odpojeno");
  }
  #endif
  #endif

  delay(100);
  delay(SLEEP_SEC);
}

// funcke pro odeslani dat na TMEP.cz
#ifdef tmep
void sendhttpGet(String httpGet)
{
  HTTPClient http;
      
  // odeslani dat 
  String serverPath = httpGet; 
  
  // zacatek http spojeni
  http.begin(serverPath.c_str());
  
  // http get request
  int httpResponseCode = http.GET();
  
  if (httpResponseCode>0) 
  {
    Serial.print("HTTP odpoved: ");
    Serial.println(httpResponseCode);
    String payload = http.getString();
    Serial.println(payload);
  }
  else 
  {
    Serial.print("Error kod: ");
    Serial.println(httpResponseCode);
  }
  // Free resources
  http.end();
}
#endif

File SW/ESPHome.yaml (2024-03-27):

substitutions:
  device_name: air-quality
  wifi_ssid: !secret wifi_ssid
  wifi_password: !secret wifi_password
  api_password: !secret api_password
  ota_password: !secret ota_password
  
globals:
   - id: max_brightness
     type: float
     restore_value: no
     initial_value: '0.5'
   - id: min_brightness
     type: float
     restore_value: no
     initial_value: '0.1'

esphome:
  name: ${device_name}
  comment: IKEA LaskaKit ESP-VINDRIKTNING ESP-32 I2C
  on_boot:
      - light.turn_on:
          id: status
          brightness: 0%

esp32:
  board: nodemcu-32s
  framework:
    type: arduino

wifi:
  ssid: ${wifi_ssid}
  password: ${wifi_password}
api:
  password: ${api_password}
ota:
  password: ${ota_password}

logger:

uart:
  rx_pin: 16
  tx_pin: 17
  baud_rate: 9600
  id: uart_2

sensor:
  - platform: pm1006
    pm_2_5:
      name: "Particulate Matter 2.5µm Concentration"
      id: pm
      accuracy_decimals: 1
      on_value:
        then:
        - if:
            condition:
              lambda: 'return x < 30;'
            then:
              - light.addressable_set:
                  id: status
                  range_from: 0
                  range_to: 0
                  red: 0.0
                  green: 1.0
                  blue: 0.0
                  color_brightness:  !lambda |-
                    return id(sun_elevation).state > 0 ? id(max_brightness) : id(min_brightness);
            else:
            - if:
                condition:
                  lambda: 'return x > 90;'
                then:
                - light.addressable_set:
                    id: status
                    range_from: 0
                    range_to: 0
                    red: 1.0
                    green: 0.0
                    blue: 0.0
                    color_brightness:  !lambda |-
                      return id(sun_elevation).state > 0 ? id(max_brightness) : id(min_brightness);
                else:
                - light.addressable_set:
                    id: status
                    range_from: 0
                    range_to: 0
                    red: 1.0
                    green: 0.72
                    blue: 0.0
                    color_brightness:  !lambda |-
                      return id(sun_elevation).state > 0 ? id(max_brightness) : id(min_brightness);
    uart_id: uart_2
    update_interval: 20s
  - platform: scd4x
    co2:
      name: "CO2"
      id: co2
      on_value:
        then:
        - if:
            condition:
              lambda: 'return x < 1000;'
            then:
              - light.addressable_set:
                  id: status
                  range_from: 1
                  range_to: 1
                  red: 0.0
                  green: 1.0
                  blue: 0.0
                  color_brightness:  !lambda |-
                    return id(sun_elevation).state > 0 ? id(max_brightness) : id(min_brightness);
            else:
            - if:
                condition:
                  lambda: 'return x > 1500;'
                then:
                - light.addressable_set:
                    id: status
                    range_from: 1
                    range_to: 1
                    red: 1.0
                    green: 0.0
                    blue: 0.0
                    color_brightness:  !lambda |-
                      return id(sun_elevation).state > 0 ? id(max_brightness) : id(min_brightness);
                else:
                - light.addressable_set:
                    id: status
                    range_from: 1
                    range_to: 1
                    red: 1.0
                    green: 0.72
                    blue: 0.0
                    color_brightness:  !lambda |-
                      return id(sun_elevation).state > 0 ? id(max_brightness) : id(min_brightness);
    humidity:
      name: "Humidity"    
      id: humidity
      on_value:
        then:
        - if:
            condition:
              lambda: 'return x < 30;'
            then:
              - light.addressable_set:
                  id: status
                  range_from: 2
                  range_to: 2
                  red: 1.0
                  green: 0.0
                  blue: 0.0
                  color_brightness:  !lambda |-
                    return id(sun_elevation).state > 0 ? id(max_brightness) : id(min_brightness);
            else:
            - if:
                condition:
                  lambda: 'return x > 60;'
                then:
                - light.addressable_set:
                    id: status
                    range_from: 2
                    range_to: 2
                    red: 0.0
                    green: 0.0
                    blue: 1.0
                    color_brightness:  !lambda |-
                      return id(sun_elevation).state > 0 ? id(max_brightness) : id(min_brightness);
                else:
                - light.addressable_set:
                    id: status
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

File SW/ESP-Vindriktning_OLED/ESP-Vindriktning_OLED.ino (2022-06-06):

#include "pm1006.h"
#include <Adafruit_NeoPixel.h>
#include <SensirionI2CScd4x.h>
#include <Wire.h>
#include <SPI.h>
#include <Adafruit_GFX.h>
#include <Adafruit_SSD1306.h>

#define PIN_FAN 12
#define PIN_LED 25
#define RXD2 16
#define TXD2 17
#define SCREEN_WIDTH  128 // OLED display width, in pixels
#define SCREEN_HEIGHT 32 // OLED display height, in pixels
#define OLED_RESET    -1 // Reset pin # (or -1 if sharing Arduino reset pin)
#define SCREEN_ADDRESS 0x3C ///< See datasheet for Address; 0x3D for 128x64, 0x3C for 128x32
Adafruit_SSD1306 display(SCREEN_WIDTH, SCREEN_HEIGHT, &Wire, OLED_RESET);


#define BRIGHTNESS 10
#define SLEEP_SEC 5*60

#define PM_LED 1
#define TEMP_LED 2
#define CO2_LED 3

static PM1006 pm1006(&Serial2);
Adafruit_NeoPixel rgbWS = Adafruit_NeoPixel(3, PIN_LED, NEO_GRB + NEO_KHZ800);
SensirionI2CScd4x scd4x;

void setup() {
  pinMode(PIN_FAN, OUTPUT); // Fan
  rgbWS.begin(); // WS2718
  rgbWS.setBrightness(BRIGHTNESS);
  
  Serial.begin(115200);
  Serial2.begin(9600, SERIAL_8N1, RXD2, TXD2);

  // SSD1306_SWITCHCAPVCC = generate display voltage from 3.3V internally
  if(!display.begin(SSD1306_SWITCHCAPVCC, SCREEN_ADDRESS)) {
    Serial.println(F("SSD1306 allocation failed"));
    for(;;); // Don't proceed, loop forever
  }



  // Clear the buffer
  display.clearDisplay();

  Wire.begin();
  uint16_t error;
  char errorMessage[256];
  scd4x.begin(Wire);
  
  Serial.println("Start...");
  delay(500);
  Serial.println("1. LED Green");
  setColorWS(0, 255, 0, PM_LED);
  delay(1000);
  Serial.println("2. LED Green");
  setColorWS(0, 255, 0, 2);
  delay(1000);
  Serial.println("3. LED Green");
  setColorWS(0, 255, 0, 3);
  delay(1000);
  setColorWS(0, 0, 0, 1);
  setColorWS(0, 0, 0, 2);
  setColorWS(0, 0, 0, 3);

  // stop potentially previously started measurement
  error = scd4x.stopPeriodicMeasurement();
  if (error) {
      Serial.print("SCD41 Error trying to execute stopPeriodicMeasurement(): ");
      errorToString(error, errorMessage, 256);
      Serial.println(errorMessage);
      alert(CO2_LED);
  }

  uint16_t serial0;
  uint16_t serial1;
  uint16_t serial2;
  error = scd4x.getSerialNumber(serial0, serial1, serial2);
  if (error) {
      Serial.print("SCD41 Error trying to execute getSerialNumber(): ");
      errorToString(error, errorMessage, 256);
      Serial.println(errorMessage);
      alert(CO2_LED);
  } else {
      printSerialNumber(serial0, serial1, serial2);
  }

  // Start Measurement
  error = scd4x.startPeriodicMeasurement();
  if (error) {
      Serial.print("SCD41 Error trying to execute startPeriodicMeasurement(): ");
      errorToString(error, errorMessage, 256);
      Serial.println(errorMessage);
      alert(CO2_LED);
  }

  Serial.println("Waiting for first measurement... (5 sec)");
}

void loop() {
  uint16_t error;
  char errorMessage[256];

  digitalWrite(PIN_FAN, HIGH);
  Serial.println("Fan ON");
  delay(10000);

  uint16_t pm2_5;
  if (pm1006.read_pm25(&pm2_5)) {
    printf("PM2.5 = %u\n", pm2_5);
  } else {
    Serial.println("Measurement failed!");
    alert(PM_LED);
  }

  delay(1000);
  digitalWrite(PIN_FAN, LOW);
  Serial.println("Fan OFF");
  
  uint16_t co2;
  float temperature;
  float humidity;
  error = scd4x.readMeasurement(co2, temperature, humidity);
  if (error) {
    Serial.print("SCD41 Error trying to execute readMeasurement(): ");
    errorToString(error, errorMessage, 256);
    Serial.println(errorMessage);
    alert(CO2_LED);
  } else if (co2 == 0) {
    Serial.println("Invalid sample detected, skipping.");
  } else {
    //temperature = temperature -4.0;
    
    Serial.print("Co2:");
    Serial.print(co2);
    Serial.print("\t");
    Serial.print(" Temperature:");
    Serial.print(temperature);
    Serial.print("\t");
    Serial.print(" Humidity:");
    Serial.println(humidity);

    if(co2 < 1000){
      setColorWS(0, 255, 0, CO2_LED);
    }
    
    if((co2 >= 1000) && (co2 < 1200)){
      setColorWS(128, 255, 0, CO2_LED);
    }
    
    if((co2 >= 1200) && (co2 < 1500)){
    setColorWS(255, 255, 0, CO2_LED);
    }
    
    if((co2 >= 1500) && (co2 < 2000)){
      setColorWS(255, 128, 0, CO2_LED);
    }
    
    if(co2 >= 2000){
      setColorWS(255, 0, 0, CO2_LED);
    }

    if(temperature < 23.0){
      setColorWS(0, 0, 255, TEMP_LED);
    }

    if((temperature >= 23.0) && (temperature < 28.0)){
      setColorWS(0, 255, 0, TEMP_LED);
    }

    if(temperature >= 28.0){
      setColorWS(255, 0, 0, TEMP_LED);
    }
  }

  // PM LED
  if(pm2_5 < 30){
    setColorWS(0, 255, 0, PM_LED);
  }
  
  if((pm2_5 >= 30) && (pm2_5 < 40)){
    setColorWS(128, 255, 0, PM_LED);
  }
  
  if((pm2_5 >= 40) && (pm2_5 < 80)){
  setColorWS(255, 255, 0, PM_LED);
  }
  
  if((pm2_5 >= 80) && (pm2_5 < 90)){
    setColorWS(255, 128, 0, PM_LED);
  }
  
  if(pm2_5 >= 90){
    setColorWS(255, 0, 0, PM_LED);
  }

  display.clearDisplay();

  display.setTextSize(1);             // Normal 1:1 pixel scale
  display.setTextColor(SSD1306_WHITE);        // Draw white text
  display.setCursor(5,5);             // Start at top-left corner
  display.println(String(co2) + "ppm");
  display.setCursor(5,21);             // Start at top-left corner
  display.println(String(pm2_5) + "mg/m3");  
  display.setCursor(69,5);             // Start at top-left corner
  display.println(String(temperature) + "degC");  
  display.setCursor(85,21);             // Start at top-left corner
  display.println(String(humidity) + "%");

  display.display();  

  delay(1);
  // ESP Deep Sleep 
  Serial.println("ESP in sleep mode");
  esp_sleep_enable_timer_wakeup(SLEEP_SEC * 1000000);
  esp_deep_sleep_start();
}

void alert(int id){
  int i = 0;
  while (1){
     if (i > 10){
      Serial.println("Maybe need Reboot...");
      //ESP.restart();
      break;
     }
     rgbWS.setBrightness(255);
     setColorWS(255, 0, 0, id); 
     delay(200);
     rgbWS.setBrightness(BRIGHTNESS);
     setColorWS(0, 0, 0, id);
     delay(200);
     i++;
  }
}

void setColorWS(byte r, byte g, byte b, int id) {  // r = hodnota cervene, g = hodnota zelene, b = hodnota modre, id = cislo LED v poradi, kterou budeme nastavovat(1 = 1. LED, 2 = 2. LED atd.)
  uint32_t rgb;  
  rgb = rgbWS.Color(r, g, b); // Konverze vstupnich hodnot R, G, B do pomocne promenne  
  rgbWS.setPixelColor(id - 1, rgb); // Nastavi pozadovanou barvu pro konkretni led = pozice LED zacinaji od nuly
  rgbWS.show();  // Zaktualizuje barvu
}

void printUint16Hex(uint16_t value) {
    Serial.print(value < 4096 ? "0" : "");
    Serial.print(value < 256 ? "0" : "");
    Serial.print(value < 16 ? "0" : "");
    Serial.print(value, HEX);
}

void printSerialNumber(uint16_t serial0, uint16_t serial1, uint16_t serial2) {
    Serial.print("SCD41 Serial: 0x");
    printUint16Hex(serial0);
    printUint16Hex(serial1);
    printUint16Hex(serial2);
    Serial.println();
}

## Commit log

2021-11-19 first working
    [ESP-VINDRIKTNING_no_batt.brd, ESP-VINDRIKTNING_no_batt.sch]
2021-12-08 connectors pos
    [ESP-VINDRIKTNING_no_batt.brd, ESP-VINDRIKTNING_no_batt.sch, ESP-VINDRIKTNING_no_batt_top_bom.csv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]
2022-01-06 ws2812 added
    [ESP-VINDRIKTNING_no_batt-ws2812_bottom_bom.csv, ESP-VINDRIKTNING_no_batt-ws2812_top_bom.csv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]
2022-01-12 new data
    [ESP-VINDRIKTNING_no_batt-ws2812_bottom_bom.csv, ESP-VINDRIKTNING_no_batt-ws2812_top_bom.csv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]
2022-02-04 new LEDs
2022-02-04 old version with one color led
2022-03-28 update data
    [ESP-VINDRIKTNING_no_batt-ws2812_bottom_bom.csv, ESP-VINDRIKTNING_v2_0_bottom_bom.csv, ESP-VINDRIKTNING_v2_0_top_bom.csv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]
2022-03-28 new connectors
    [ESP-VINDRIKTNING_v2_0_bottom_bom.csv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]
2022-05-30 Update ESP-Vindriktning_UART_TMEPcz.ino
    Added code for RGB LED
    1th is used for pm2.5, 2nd for temperature, 3rd for CO2
2022-11-14 Create ESP-Vindriktning_UART_TMEPcz_SHT40.ino
    LaskaKit sensor SHT40 instead of SCD41.
2022-12-21 terst data
    [ESP-VINDRIKTNING_v3_0_bom.csv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]
2023-02-10 new data and folders
    [ESP-VINDRIKTNING_v2_0_bottom_bom.csv, ESP-VINDRIKTNING_v2_0_top_bom.csv, ESP-VINDRIKTNING_v3_0_bom.csv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]
2023-02-12 Fix spelling of μŠup in the README
2023-02-18 test data update
    [ESP-VINDRIKTNING_v3_0_newusb_bottom_bom.csv, ESP-VINDRIKTNING_v3_0_newusb_top_bom.csv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]
2023-12-27 Update Vindriktning-all_in_one.ino
    Fix timer. ESP is now just waiting (delay) and it is not sleeping. It has higher consumption but it is working.
    [Vindriktning-all_in_one.ino]
2023-12-30 Fix #14 and #15 in basic example.
    [VINDRIKTNING.ino]
2024-01-22 board info added
2024-01-22 Create LaskaKit SCD41-CO2-Sensor for Vindr.step
    [LaskaKit SCD41-CO2-Sensor for Vindr.step]
2024-03-27 uart2 is reserved
    ID 'uart2' is reserved internally and cannot be used
